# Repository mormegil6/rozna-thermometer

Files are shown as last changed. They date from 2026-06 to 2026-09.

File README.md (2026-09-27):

[]() []() []() []() []() []() 

# rozna-thermometer - Rožna Arduino Thermometer

A networked temperature monitor first built in 2015 in a student dorm on Rožna
dolina (Ljubljana), revived in 2026 for reliable, unattended temperature monitoring.
An Arduino **Leonardo** reads a **DS18B20** sensor, shows the temperature and an NTP
clock on a 16x2 LCD, and serves the original jQuery-Mobile web page plus a
`/list.json` API over Ethernet (**ENC28J60**).

The 2015 code is kept as the reference; the revival modernises it for current
toolchains, fixes the one thing that never worked back then (the ENC28J60 needed a
hardware reset), and adds resilience so it can run headless and unattended.

| 2015, the original build | 2026, the revived build | 2026, the public web UI |
|:---:|:---:|:---:|
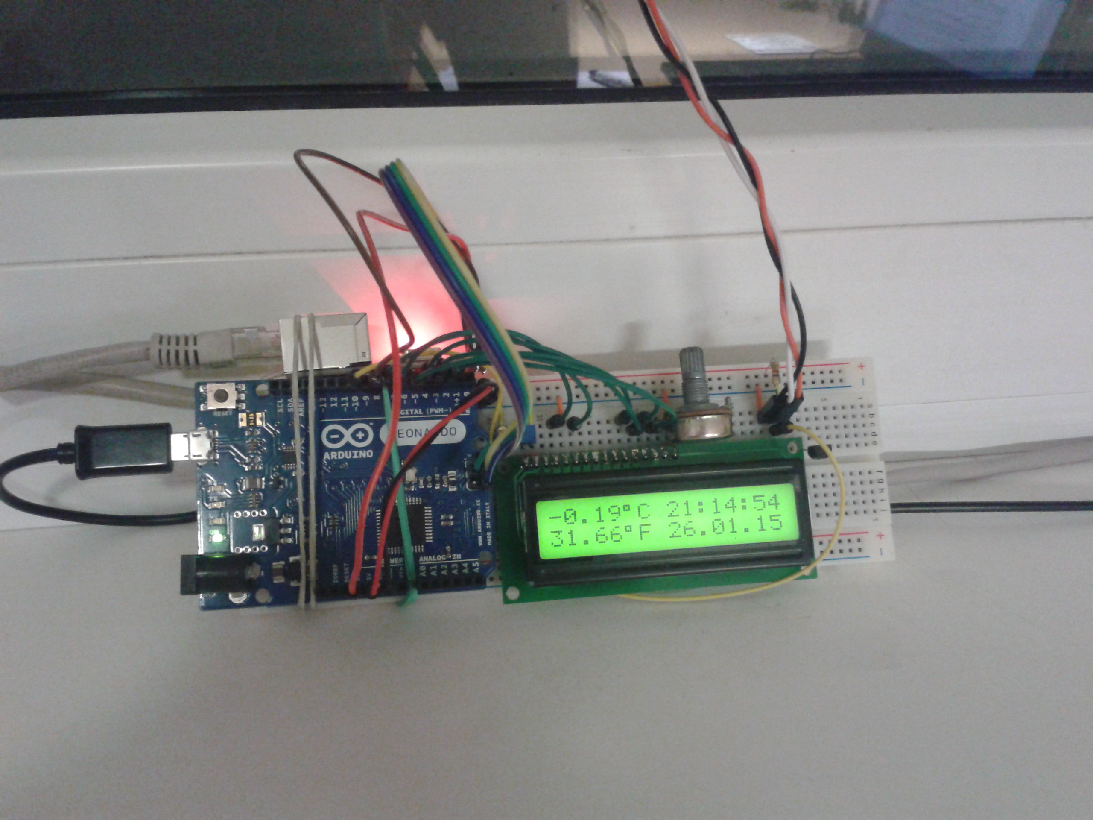
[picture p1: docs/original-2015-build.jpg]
The original 2015 breadboard build
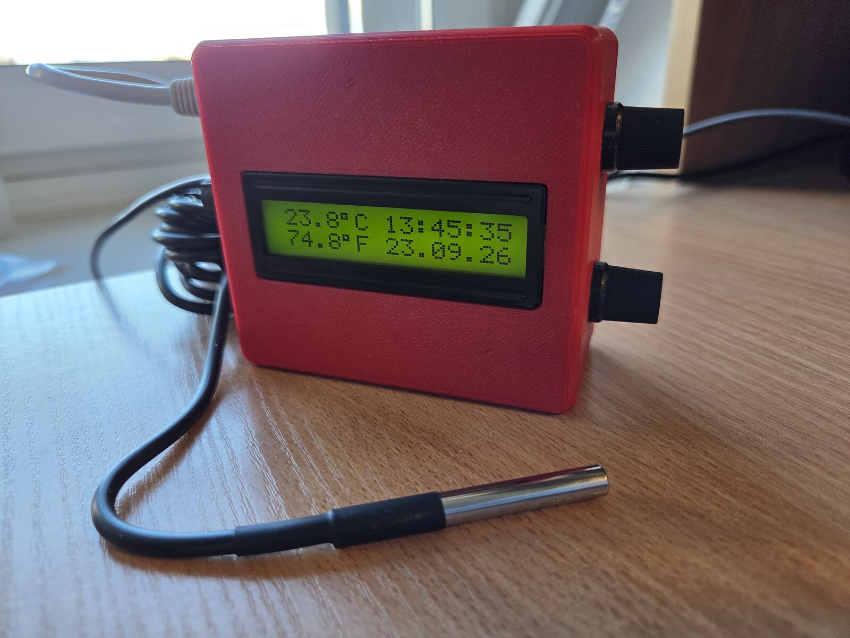
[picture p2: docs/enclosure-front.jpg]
The 2026 build in its 3D-printed enclosure, the DS18B20 probe on its cable in front
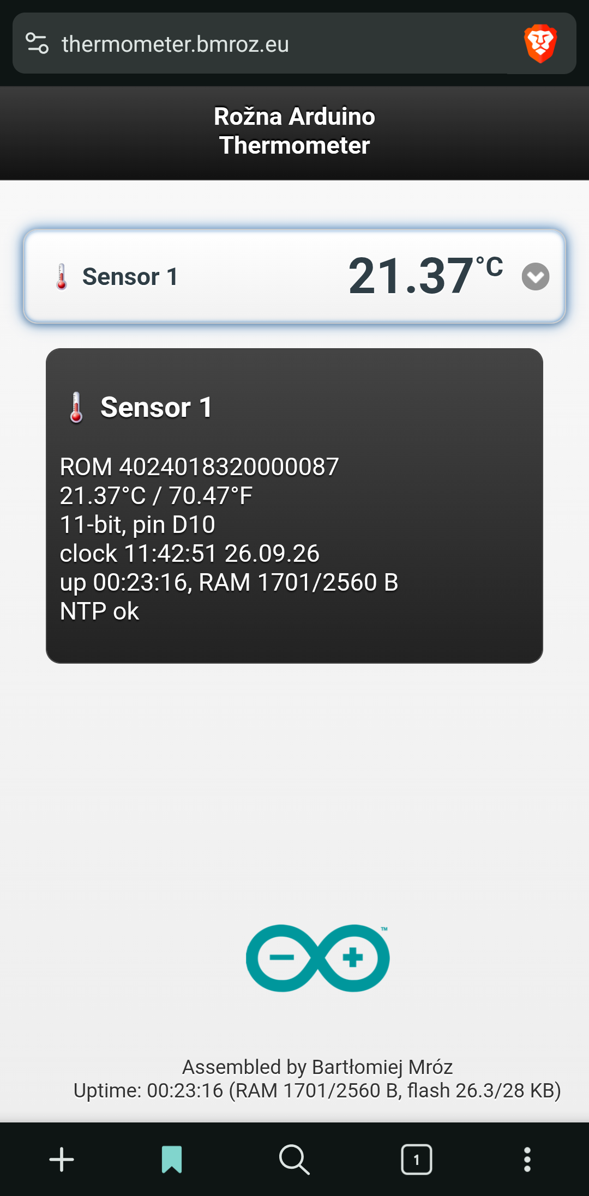
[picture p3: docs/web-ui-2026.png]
The web UI at thermometer.bmroz.eu in Brave on Android
|  |  |  |

*Left: the original 2015 build, LCD reading -0.19 C at 21:14 on 26 Jan 2015. Middle: the 2026 build in its 3D-printed enclosure, the DS18B20 probe on its cable in front. Right: the public web UI at [thermometer.bmroz.eu](https://thermometer.bmroz.eu) (Brave on Android) with a sensor's detail panel expanded. Click an image for the full size.*

## History

The original ran in a Ljubljana student dorm where the network was unusually open:
each room got two public, routable IP addresses (one per desk), so the thermometer's
page was reachable from the open internet, not just the LAN. Our room's router ran
OpenWrt with 802.1X on the WiFi, so we were the only ones online in there, which is
part of why a tiny ENC28J60 web server made sense at all. The 2026 revival runs on an
ordinary LAN, wherever it is plugged in, so the board itself is LAN-only. The page is
made public through a caching proxy and a Cloudflare tunnel on a Raspberry Pi instead
of a router port forward (see [Public access](#public-access)).

## Status

Working and validated on real hardware. The diagnostics pass, the modernised
sketch serves the original web UI and `/list.json`, NTP sets the clock, the
SleepyDog watchdog runs, and the Ethernet stack recovers from faults on its own.
Telegram alerting (Stage D) is designed but deferred (it lives off-device, on a
Raspberry Pi).

| Subsystem | State |
|---|---|
| Board, upload, Serial | working |
| 16x2 LCD (temperature + clock) | working |
| DS18B20 temperature | working |
| ENC28J60 Ethernet, web, `/list.json` | working (needs `RST` wired to D9, see below) |
| NTP clock | working |
| Watchdog and resilience | working |
| Public page, https://thermometer.bmroz.eu | working (nginx cache and Cloudflare tunnel on a Pi, see `pi/`) |
| Telegram alerting | deferred (Pi-side poller, see [Alerting](#alerting-possible-not-planned)) |

## Hardware and wiring

- **Arduino Leonardo** (ATmega32u4). Real ceilings: about 28 KB usable flash (a 4 KB
  bootloader eats into the 32 KB) and 2560 B of RAM. RAM is the tight one (the
  Ethernet buffer alone is over 1 KB).
- **ENC28J60** Ethernet module (EtherCard library)
- **DS18B20** temperature sensor (OneWire + DallasTemperature)
- **16x2 HD44780 LCD**, 4-bit, with a contrast potentiometer
- Powered over USB

### Pin map

| Signal | Leonardo pin | Notes |
|---|---|---|
| LCD | see LCD pin map below | 16x2 HD44780, 4-bit mode, `LiquidCrystal lcd(7,6,5,4,3,2)` |
| DS18B20 DATA | D10 | 4.7 kOhm pull-up DATA to 5V, required |
| ENC28J60 SPI (MISO/MOSI/SCK) | ICSP header | not pins 11/12/13 on a Leonardo |
| ENC28J60 CS | D8 | see Gotchas below |
| ENC28J60 RST | D9 | required, see Gotchas below |
| ENC28J60 VCC / GND | 3.3V (or 5V if the module has a regulator) / GND | |

**The probe plugs in through a 3.5 mm jack.** A small nod to my audio work these
days, and honestly just the first 3-pin connector that came to mind and was easy to
get. It works well, with two things to know. A plug bridges neighbouring contacts
while it is being inserted, so the layout matters for hot-plugging: tip = +5V, ring
(the middle contact) = GND, sleeve = DATA, which turns the unavoidable transient
shorts into +5V to GND and DATA to GND instead of +5V to DATA. And a series resistor
of 220 to 470 ohms in the +5V line is cheap insurance against a plug pulled out at an
angle. The 4.7 kOhm pull-up still has to bridge DATA to +5V as its own branch, not sit
in line with the signal.

### LCD pin map

| LCD signal | LCD header pin | Connects to | Notes |
|---|---|---|---|
| VSS | 1 | GND | |
| VDD | 2 | +5V | |
| V0 | 3 | contrast pot wiper | pot ends to 5V and GND |
| RS | 4 | Leonardo D7 | |
| RW | 5 | GND | not driven by the firmware, tied low |
| E | 6 | Leonardo D6 | |
| D0-D3 | 7-10 | not connected | 4-bit mode |
| D4 | 11 | Leonardo D5 | |
| D5 | 12 | Leonardo D4 | |
| D6 | 13 | Leonardo D3 | |
| D7 | 14 | Leonardo D2 | |
| A | 15 | +5V (through ~220R if the module has no onboard resistor) | backlight |
| K | 16 | GND | backlight |

**Gotchas.** The ENC28J60 needs a hardware reset: wire its `RST` to D9, or its PHY
never links (that was the 2015 "never appears on the router" bug). Keep its chip
select on D8, because EtherCard's default drifted to pin 17 on the Leonardo. Both are
set in the sketch. Connections on a breadboard are easily bumped loose, so solder or
use locking connectors for a permanent install. More in
[docs/hardware-notes.md](docs/hardware-notes.md).

### Enclosure

A 3D-printed enclosure, designed by Daniel Wiśniewski, a colleague from the
Department of Multimedia Systems, houses the board and brings the LCD, contrast
pot and brightness pot to the front panel. The two potentiometers are labelled
with brightness and contrast icons adapted from Flaticon (see [License](#license)
for credit). Design files are in [`enclosure/`](enclosure/): the full assembly
([`Termo_ass.step`](enclosure/Termo_ass.step)) and the two printable parts
([`Termo_box.stl`](enclosure/Termo_box.stl), [`Termo_lid.stl`](enclosure/Termo_lid.stl)).
A live, editable version is also on
[Fusion 360](https://mypg468.autodesk360.com/g/shares/SH28cd1QT2badd0ea72b3ebdcf2fd0c9138a).
The Leonardo's RESET button is inside the box, so a manual reset means opening the
lid (the firmware restarts itself when it has to).

| The knobs: brightness (top), contrast (bottom) | Inside, lid off (assembly, August 2026) | The lid carries the LCD (assembly, August 2026) |
|:---:|:---:|:---:|
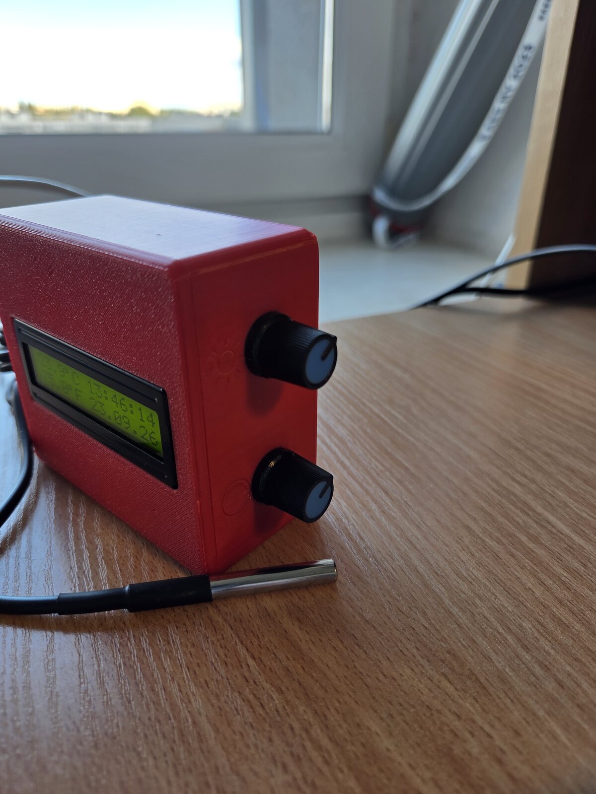
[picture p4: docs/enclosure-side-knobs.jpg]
Side of the enclosure with the brightness and contrast knobs and their embossed icons
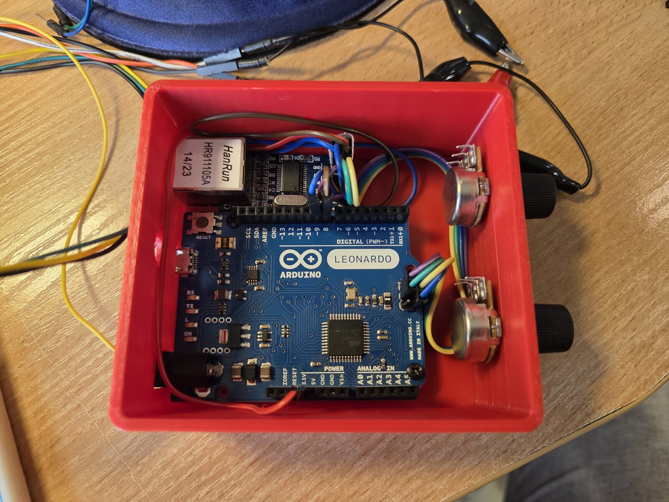
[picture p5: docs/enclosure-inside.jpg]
Inside the box: Leonardo, ENC28J60 module and the two potentiometers
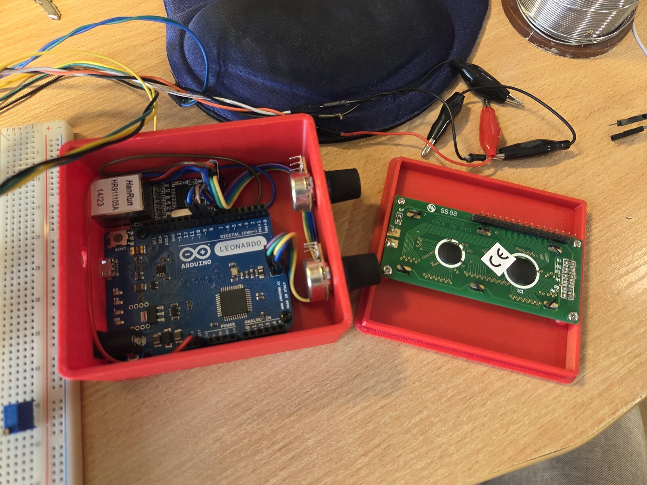
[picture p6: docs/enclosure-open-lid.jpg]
The open lid with the LCD's back and header
|  |  |  |

It is cramped and not pretty inside. These two were taken during assembly, before the
lid went on. The LCD's pin header was removed and wires were soldered straight to its
pads, because the header pins stuck out too far and collided with the Arduino's pin
sockets.

| Mid-wiring, wires soldered straight to the LCD (August 2026) | Wired up right before closing the lid (August 2026) |
|:---:|:---:|
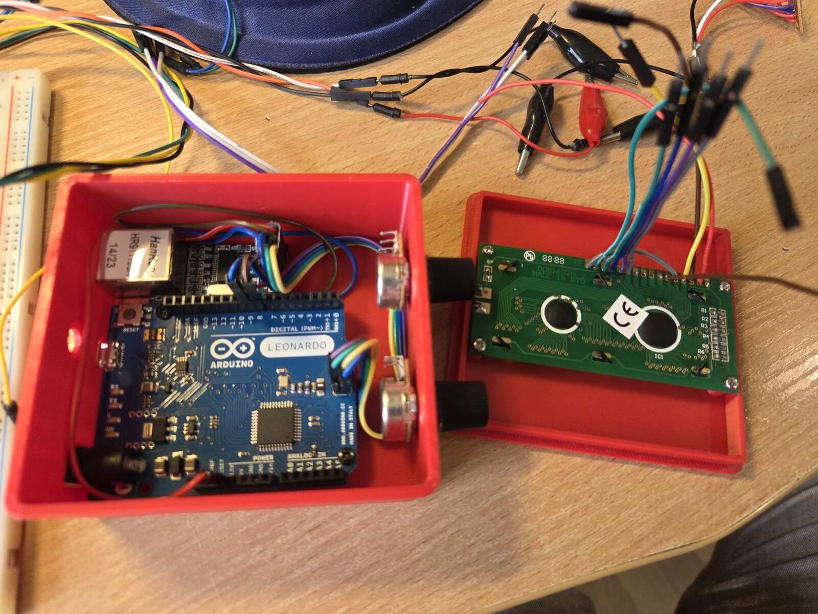
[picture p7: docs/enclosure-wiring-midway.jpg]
Box open with wires soldered directly to the LCD pads
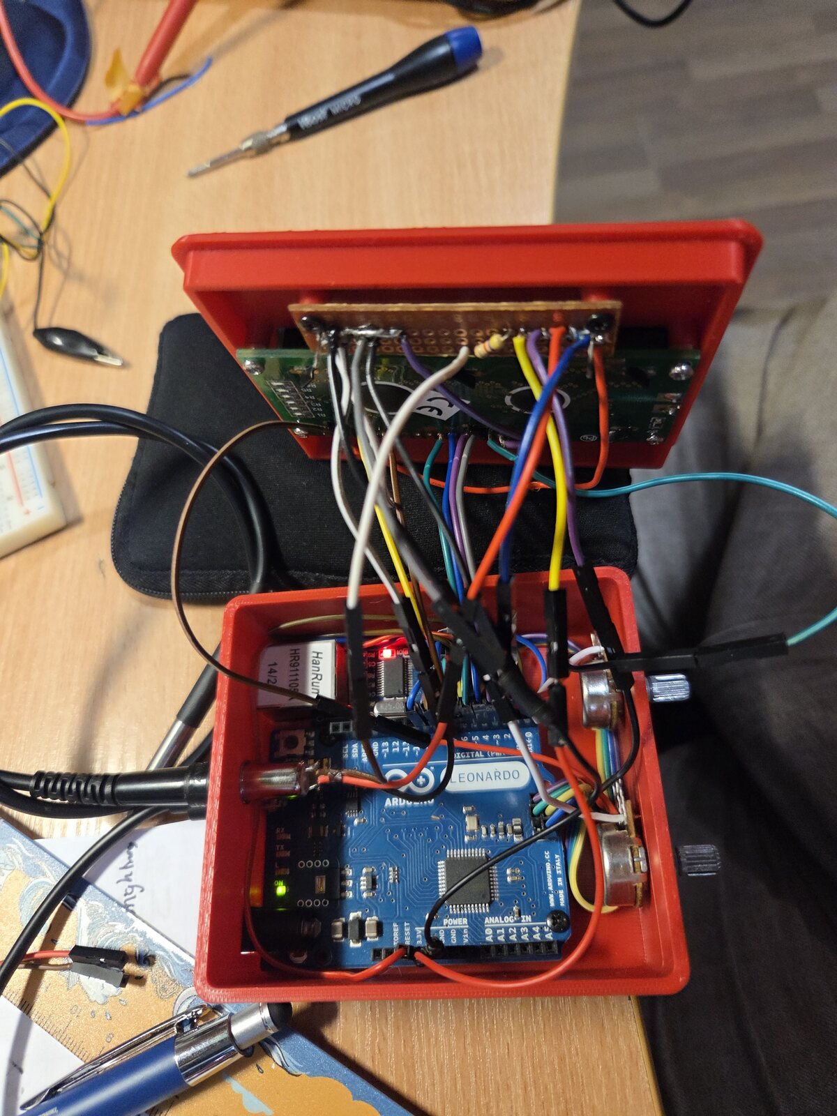
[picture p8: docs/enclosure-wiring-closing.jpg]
The finished wiring inside the box just before the lid was closed
|  |  |

## How it works

The Arduino serves the original 2015 jQuery-Mobile page (`/`, `main.css`, `main.js`,
`det.js`, `/favicon.svg`) and a `/list.json` API with the temperature and the health
fields. The heavy jQuery and jQuery-Mobile files load from `code.jquery.com`, because
284 KB would never fit in 28 KB of flash. The clock comes from NTP with a fixed server
IP (a DNS lookup used to freeze the whole loop), and EU summer time is computed on the
board. Sensor reads are asynchronous, so nothing waits on a 750 ms conversion. Details
and the JSON fields: [docs/how-it-works.md](docs/how-it-works.md).

### Resilience

The ENC28J60 is the weak link, so the firmware is built to survive it and to recover
without a person:

- A hardware reset over `RST` (D9) and a bounded SPI and oscillator check before
  `ether.begin()`, so a dead NIC never hangs the board. The LCD and the sensor keep
  working, and the NIC is retried every 15 s.
- The NIC is never re-initialised in place after traffic (EtherCard cannot resync its
  receive pointers). Instead a gateway ARP round trip proves the network path, and a
  watchdog restart of the MCU (about 5 s) follows 5 minutes of silence (2 once the chip has flagged a receive overflow) or 3 minutes
  without a link.
- The chip's key registers are checked every 10 s. The evidence (`rst`, `why`, `dbg`)
  survives a restart and is served in `/list.json`.
- Two LCD status cells stay blank when all is well: row 1 character 8 counts recent
  self-restarts, row 2 character 8 shows `O` (NIC offline), `L` (no link) or `S` (link
  up, no gateway reply).
- The DS18B20 can be plugged in at any time.

Full description: [docs/resilience.md](docs/resilience.md).

### Public access

The page is public at https://thermometer.bmroz.eu, but visitors never reach the
Arduino:

```
visitor -> Cloudflare (HTTPS) -> cloudflared on the Pi -> nginx cache on the Pi (127.0.0.1:8081) -> Arduino
```

A Raspberry Pi on the same LAN answers visitors from a cache and forwards about one
request per 10 s to the board, however many people watch. No router port is
forwarded, and none should be: the board speaks plain HTTP with no authentication.
Configs and setup steps: [pi/](pi/README.md).

## Build and upload

Built with **arduino-cli 1.5.1**, core **arduino:avr 1.8.8**, FQBN
`arduino:avr:leonardo`. Libraries:

| Library | Version |
|---|---|
| OneWire | 2.3.8 |
| DallasTemperature | 4.0.6 |
| EtherCard | 1.1.0 |
| Adafruit SleepyDog Library | 1.8.4 |
| Time | 1.6.1 |
| LiquidCrystal | 1.0.7 |

Footprint: about 26.3 KB of 28 KB flash (93 %), about 1.6 KB of 2.5 KB RAM (65 %).

```sh
# one-time setup
arduino-cli core install arduino:avr
arduino-cli lib install OneWire DallasTemperature EtherCard "Adafruit SleepyDog Library" Time LiquidCrystal

# find the port
arduino-cli board list                        # e.g. /dev/cu.usbmodem1101

# compile THEN upload (arduino-cli upload does NOT recompile, so always compile first)
arduino-cli compile -b arduino:avr:leonardo firmware/TempServerJQuery
arduino-cli upload  -b arduino:avr:leonardo -p <PORT> firmware/TempServerJQuery

# watch Serial at 9600
arduino-cli monitor -p <PORT> -c baudrate=9600
```

Bring up the subsystems first with the `diagnostics/` sketches (upload each, read
Serial), then flash the main sketch.

**If upload fails** with `butterfly_recv ... failed`, the Leonardo's 1200-baud
auto-reset did not reach the bootloader. See [docs/flashing.md](docs/flashing.md).

## Configuration (top of the sketch)

| Macro | Default | Meaning |
|---|---|---|
| `ETH_ENABLED` | `1` | `0` runs it as a pure thermometer, no NIC access at all |
| `USE_NTP` | `1` | `0` skips NTP and DNS; the LCD shows uptime and the web never stalls |
| `DEBUG` | `0` | `1` prints a 3 s Serial heartbeat; `0` is quiet and leaner |
| `SENSOR_RES` | `11` | DS18B20 resolution bits 9 to 12 (11 is 0.125 C, about 375 ms) |
| `CS_PIN` | `8` | ENC28J60 chip-select |
| `ETH_RST_PIN` | `9` | ENC28J60 hardware reset (comment out if unwired) |
| `ONE_WIRE_BUS` | `10` | DS18B20 data pin |
| `mymac` | `02:52:6F:7A:6E:61` | locally-administered MAC |
| `myip` / `gwip` / `dnsip` / `mask` | `192.168.1.200` / `.1` / `.1` / `/24` | the network it is deployed on |
| `UTC_STD_OFFSET_SEC` | `1*3600` | CET (winter) offset; EU summer time is added automatically |
| `PROBE_MS` / `AUDIT_MS` / `SILENT_RESTART_MS` / `SILENT_FAST_MS` / `LINK_DOWN_RESTART_MS` | 30 s / 10 s / 5 min / 2 min / 3 min | gateway ARP probe and chip register check intervals, then MCU restart when the gateway never replies or the link is lost |
| `ASSET_VER` | `"9"` | cache-bust version; bump when main.css/main.js/det.js change |
| `FOOTER_LOGO_URL` | ImgBB link | footer logo image |

For bench testing on a different subnet, change `myip` / `gwip` / `dnsip` (for
example to `192.168.0.x`).

## Diagnostics

Upload each, read Serial at 9600. Pass criteria:

| Sketch | Pass |
|---|---|
| `diag_01_blink` | on-board "L" LED blinks about 1 Hz; Serial prints `tick N` |
| `diag_02_lcd` | LCD shows `Rozna Thermo OK` and a live counter (adjust contrast if blank) |
| `diag_03_ds18b20` | `Found N device(s)`, a `28...` ROM with `CRC OK`, a plausible temperature |
| `diag_04_ethernet` | `ENC28J60 found, rev N`, IP set, `Link: UP`, answers `ping` |

## What changed since the 2015 code

The 2015 architecture was sound and is largely preserved. The changes are a few
modernisations, NTP instead of a serial time-sync, and a lot of reliability work (the
hardware reset was the real 2015 fix). See
[docs/changes-since-2015.md](docs/changes-since-2015.md).

## Known issues

- The ENC28J60 module is the weak link. Its 25 MHz oscillator can be intermittent (a
  cold solder joint on the crystal or its caps, or marginal power); a power-cycle plus
  the RST pulse revives it. If it stays flaky, reflow the crystal joints or replace
  the module (about 3 USD); the firmware and EtherCard code are unchanged either way.
- Latency is jittery (it is a slow 10 Mbps chip on breadboard wiring) but lossless
  once connected.
- Field failures on 2026-09-25 and 2026-09-26, cause not yet proven: the board stops
  answering ARP and TCP until it is restarted. The gateway ARP round trip now detects
  it and restarts the board by itself (it did on 09-26, after about 5 minutes), and the
  saved chip snapshot narrows the cause. Details in
  [docs/resilience.md](docs/resilience.md#field-failure-2026-09-25).
- The ENC28J60 module is powered from the Leonardo's 3.3 V pin, documented for only
  about 50 mA against 120 to 200 mA for the chip once linked. On 2026-09-26 its
  registers were repeatedly scrambled while the MCU kept running; the firmware
  restarted itself each time. A separate 3.3 V regulator for the module is the likely
  fix. Details in [docs/resilience.md](docs/resilience.md#chip-state-corruption-2026-09-26-hardware-suspected).
- A static-IP ENC28J60 takes no DHCP lease, so it might not appear in the router's
  device list; some routers list it anyway from ARP traffic they have seen. `ping`
  is the reliable check either way.

## Alerting (possible, not planned)

The ENC28J60 cannot do TLS, so the Arduino cannot call Telegram (HTTPS only)
directly. If this is ever wanted, a small poller on the Raspberry Pi that already
serves the public page (see [pi/](pi/README.md)) could fetch `/list.json` and send
an alert when the temperature crosses a threshold, keeping the Arduino dumb and
reusing infrastructure that already exists. Not being built right now.

## Repository layout

```
firmware/TempServerJQuery/TempServerJQuery.ino   the modernised sketch (static IP)
diagnostics/diag_01_blink/ ... diag_07_.../     bring-up and hardware diagnostic sketches
original-2015/                                    the untouched 2015 sketches (reference)
pi/                                               nginx cache and Cloudflare tunnel config for public access
enclosure/                                        enclosure design files (STEP, STL)
ardu_tempserver_logos/                            logo/icon source files
docs/                                             README images and the detailed notes
README.md  LICENSE  .gitignore
```

## License

MIT. See [LICENSE](LICENSE). The Arduino libraries this builds against are not
included and remain under their own licenses. The enclosure's brightness and
contrast icons are adapted from Flaticon: [Brightness icon](https://www.flaticon.com/free-icon/brightness_466300)
by Freepik, [Contrast icon](https://www.flaticon.com/free-icon/contrast_475980)
by Smartline, used under Flaticon's free license and not covered by the MIT
license above.

## Contact

Bartłomiej Mróz · bartlomiej.mroz@pg.edu.pl · Department of Multimedia Systems, Gdańsk University of Technology · [bmroz.eu](https://bmroz.eu)

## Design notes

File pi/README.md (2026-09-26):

# Pi side: public access without exposing the Arduino

The thermometer page is public at https://thermometer.bmroz.eu, but visitors never
reach the Arduino. A Raspberry Pi on the same LAN answers them from a cache and
forwards only a trickle of requests to the board.

```
visitor -> Cloudflare (HTTPS) -> cloudflared on the Pi -> nginx cache on the Pi (127.0.0.1:8081) -> Arduino (192.168.1.200)
```

The Arduino still serves the page, the scripts and `/list.json`. The Pi only caches
and relays. Nothing here changes the firmware.

## Why a cache is needed

The ENC28J60 is a 10 Mbit chip with one 1150 byte buffer, and every open browser tab
polls `/list.json` every 15 s. A handful of visitors, or one scanner, would keep it
busy or knock it over. With the cache in front, the board sees about one request per
10 s however many people watch.

What `nginx/thermometer.conf` and `nginx/thermo-proxy.conf` do:

- Listen on 127.0.0.1:8081 only. The Cloudflare tunnel is the only client.
- Proxy only the board's six URLs (`/`, `/list.json`, `/main.css`, `/main.js`,
  `/det.js`, `/favicon.svg`) and only GET. Everything else is refused by nginx itself
  (404, 400 or 403) and never reaches the board.
- Cache `/list.json` for 10 s, `/` for 60 s and the assets for 10 min (keyed by the
  `?v=` value, which must be 0 to 3 digits, so bumping `ASSET_VER` still works).
  Query strings on the other URLs are ignored, so they cannot bypass the cache.
- Collapse simultaneous cache misses into one request (`proxy_cache_lock`).
- Hold at most 2 connections open to the board (`max_conns=2`).
- Limit each visitor to 5 requests per second, burst 20, then answer 429. The visitor
  address comes from the `CF-Connecting-IP` header, trusted only from 127.0.0.1.
- Send the board a minimal request (`proxy_pass_request_headers off`). Cloudflare adds
  many headers, and the board's receive buffer is small.
- Keep the cache in RAM (`/dev/shm`) and write no access log.

Tested on the Pi: 800 requests from 800 different client addresses, 40 at a time,
caused exactly one request to the board. One address sending 100 requests as fast as
possible got 25 answers and 75 429s.

## Setup (Raspberry Pi OS or Debian, as root or with sudo)

### 1. nginx

```sh
sudo apt-get install nginx
sudo rm -f /etc/nginx/sites-enabled/default      # nothing should listen on port 80
sudo install -m 644 pi/nginx/thermometer.conf   /etc/nginx/conf.d/thermometer.conf
sudo install -m 644 pi/nginx/thermo-proxy.conf  /etc/nginx/snippets/thermo-proxy.conf
sudo nginx -t && sudo systemctl reload nginx
curl -i http://127.0.0.1:8081/list.json          # run twice: X-Cache goes MISS, then HIT
```

The board's address is in `thermometer.conf` (`192.168.1.200`) and in
`thermo-proxy.conf` (the `Host` header). Change both if the board's IP changes.

### 2. cloudflared

Debian has no `cloudflared` package, so add Cloudflare's own apt repository:

```sh
sudo mkdir -p --mode=0755 /usr/share/keyrings
curl -fsSL https://pkg.cloudflare.com/cloudflare-public-v2.gpg | sudo tee /usr/share/keyrings/cloudflare-public-v2.gpg >/dev/null
echo "deb [signed-by=/usr/share/keyrings/cloudflare-public-v2.gpg] https://pkg.cloudflare.com/cloudflared any main" | sudo tee /etc/apt/sources.list.d/cloudflared.list
sudo apt-get update && sudo apt-get install cloudflared
```

The domain's DNS must already be on Cloudflare. Then:

```sh
cloudflared tunnel login                 # prints a link; open it, pick the domain, authorize
cloudflared tunnel create thermometer    # prints the tunnel id, writes ~/.cloudflared/<id>.json
cloudflared tunnel route dns thermometer thermometer.bmroz.eu    # creates the CNAME
sudo mkdir -p /etc/cloudflared
sudo install -m 600 -o root -g root ~/.cloudflared/<id>.json /etc/cloudflared/<id>.json
# write /etc/cloudflared/config.yml from pi/cloudflared/config.yml.example, then:
sudo cloudflared service install
systemctl is-active cloudflared          # active
curl -i https://thermometer.bmroz.eu/list.json
```

`cert.pem` from the login lets the Pi create tunnels and DNS records for the whole
domain, and the running tunnel does not need it. Delete `~/.cloudflared/cert.pem`
once the tunnel works and log in again only when you add another hostname.

## Do not

- Forward a router port straight to the Arduino. It speaks plain HTTP with no
  authentication and a tiny TCP stack.
- Point anything public at the Arduino's address instead of the Pi.

## Behaviour when the board is down

After the 10 s cache expires visitors get an error from nginx. An already open page
keeps showing its last reading and retries every 15 s; it has no "stale" marker, so
the footer uptime standing still is the only hint.

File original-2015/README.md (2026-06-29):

# Original 2015 sketches (historical reference)

These are the untouched sketches from the 2015 build, kept to show how the project
evolved. They are not maintained and will not necessarily compile against current
libraries. For the working firmware see [`../firmware/TempServerJQuery/`](../firmware/TempServerJQuery/).

In date order (the commit dates match these):

| Date | File | What it was |
|---|---|---|
| 2015-01-25 | `thermometr_01.ino` | The earliest sketch: an LCD-only thermometer (C / F), no networking. |
| 2015-01-26 | `Exosite_tempServ.ino` | A variant that pushed readings to the Exosite IoT cloud (since defunct). |
| 2015-01-27 | `JQueryOrig.ino` | The jQuery-Mobile web UI (header "Is it hot?"), no LCD; DHCP or static IP selectable. |
| 2015-01-27 | `temp_server.ino` | A plain HTTP page ("My Arduino Website / Hello!"). |
| 2015-02-05 | `TempServerJQuery.ino` | The most complete variant: jQuery-Mobile UI + 16x2 LCD + clock + `/list.json`. The 2026 firmware is based on this one. |
| 2015-05-04 | `TempServerJQuery_noethernet.ino` | Same as above with Ethernet commented out, for LCD and clock bench testing. |

The file [`build-notes-2015.txt`](build-notes-2015.txt) is the original parts list from 2015
(the DS18B20 sensor, the LCD that sat on the window, the Arduino Leonardo, the ENC28J60
module, and the OpenWrt TP-LINK WR1043ND v2 router), together with the shell one-liner that
pushed the current time to the board over the serial port. The link shortener it used is long
dead, but the note is kept as found.

See the main [README](../README.md), section "What changed since the 2015 code", for the details.

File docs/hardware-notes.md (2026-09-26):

# Hardware notes

Wiring gotchas that cost time during bring-up. The pin maps are in the [README](../README.md#hardware-and-wiring).

**CS gotcha.** EtherCard's `begin()` default chip-select drifted from pin 8 (old)
to `SS`, which is pin 17 on the Leonardo (current library). The 2015 sketch relied
on the old default, so the real wiring is CS=8. The sketch sets `CS_PIN 8`
explicitly.

**RST gotcha (the actual 2015 bug).** The ENC28J60 needs a hardware reset pulse or
its PHY will not link. That was the original "never appears on the router" symptom.
Wire `RST` to D9; the firmware pulses it before every `ether.begin()`. Note that SPI
register reads are clocked by the Arduino, so the chip answers SPI even when its own
25 MHz crystal is not running. The firmware therefore also checks the
oscillator-ready bit (`CLKRDY`) before trusting it.

**Solid connections matter.** On a breadboard with dupont wires, bumping the board
can knock the ENC's SPI or power loose (this happened repeatedly during bring-up).
For a permanent install, solder or use locking connectors on the ENC's SPI, power
and RST lines.

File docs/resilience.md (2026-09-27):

# Resilience

How the firmware survives a flaky ENC28J60 and recovers without a person. The summary is in the
[README](../README.md#how-it-works).

## What it does

- Hardware reset of the ENC28J60 (`RST` to D9) before every bring-up.
- A bounded SPI plus CLKRDY probe before `ether.begin()`. `begin()` spins forever on
  an unresponsive chip, so it is never called unless the chip answers and its
  oscillator is running. A missing or dead NIC drops to OFFLINE: the LCD and sensor
  keep working and the firmware retries the NIC every 15 s.
- The NIC is never re-initialised in place once it may have received a frame.
  EtherCard keeps its receive pointers in function-local statics that
  `ether.begin()` cannot reset, so an in-place re-init leaves the receive path out of
  step with the chip: the board still transmits but never answers ARP or ping. A lost
  link is simply waited out (the receive ring is untouched), and if the chip does not
  resume when the link returns, the ladder below restarts the MCU.
- Recovery ladder. With the link up the board sends an ARP request to the gateway
  every 30 s, and only the gateway's reply counts as proof of life: it needs a short
  frame to leave the board and a reply to come back, whereas any received frame would
  hide a chip that receives but cannot send. The MCU restarts with a watchdog reset
  (about 5 s, which also clears the EtherCard pointers) after 5 min without a reply (2 min once the chip has flagged a receive
  overflow),
  3 min with the link down after it was up, a NIC fault after traffic, or the chip's
  key registers (ECON1.RXEN, MACON1, MACON3, ERXFCON, the MAC address) changing on two
  checks 10 s apart. Consecutive restarts stretch the windows up to 4 times, and 30
  min of healthy uptime forgets them. The clock survives a restart. `gwip` must
  answer ARP, otherwise a bench board with no gateway restarts at 5, 10 and then every 20 min.
- Evidence for the next failure. Before a self-restart the chip's registers are read
  (12 bytes: ECON1 ESTAT EIR MACON1 MACON3 ERXFCON, a mask of wrong MAC bytes,
  EPKTCNT, then the receive buffer pointers ERXRDPT and ERXWRPT, low byte first),
  printed on Serial, kept in RAM across the restart and served as `why` and `dbg` in
  `/list.json`. The read restores ECON1.BSEL, so EtherCard's cached register bank
  stays valid. At every boot Serial shows `Chip audit OK` when the registers match
  what EtherCard configured, or `Chip audit BAD` with the bytes. The chip's own reset
  clears its sticky error flags (EIR.RXERIF, EIR.TXERIF, ESTAT.BUFER), so a flag seen
  later means an overflow or error since the last bring-up. Serial also prints the
  link changes with the uptime, the snapshot when the first gateway probe goes
  unanswered, a one-time "RX overflow flag" line, and a snapshot whenever you send `d`
  over USB.
- Receive buffer pointer. ENC28J60 errata item 14 says an even ERXRDPT can corrupt
  the receive buffer, including the next packet pointer of a frame. EtherCard's
  `initialize()` leaves ERXRDPT at 0, and its own steady state writes only odd values
  (next packet pointer minus 1, or ERXND). After every successful `ether.begin()` the
  sketch therefore writes ERXRDPT = ERXND (0x0BFF), the value EtherCard itself writes
  when the next packet is at 0, so the first frames after a bring-up no longer arrive
  with an even pointer. Whether this was behind the 09-25 and 09-26 failures is
  unproven.
- LCD status cells, both blank when all is well: row 0 column 8 shows recent
  self-restarts (`+` above 9) and clears itself after 30 min of healthy uptime, row 1
  column 8 is `O` for NIC offline, `L` for no link and `S` for link up but no
  gateway ARP reply for 90 s. The lifetime restart count is `rst` in `/list.json`.
- The DS18B20 can be plugged in at any time. DallasTemperature only counts devices in
  `begin()`, so a probe attached after boot used to stay invisible; while none is
  known the sketch checks the bus every 3 s and re-runs `begin()` when one appears.
- SleepyDog watchdog (8 s), safe on the 32u4 bootloader.
- Temperature and LCD are fully decoupled from the network, so the monitor always
  works.

## Field failure, 2026-09-25

Cause not yet proven: LCD, clock and link LEDs
fine, but the board answered ping (with a static ARP entry) and never answered ARP
or completed a TCP handshake, from wired and Wi-Fi clients alike. Every frame the
firmware sends with an explicit short length (the 42 byte ARP reply, the SYN-ACK)
was lost, while echo replies, which copy the incoming length, were fine. The
suspect is the chip no longer padding short frames (MACON3), so the router drops
them; a power cycle fixed the same symptom the day before. The gateway ARP round
trip now detects it and the register snapshot should show which register changed.

## Second occurrence, 2026-09-26, and the first recovery in the field

After a reflash the board booted with no Ethernet cable, and the cable was plugged in
about a minute later. For the next five minutes the board sent an ARP request for the
gateway every 3 s or so (visible on the LAN) but answered nothing, so there was no ping,
no web page and no NTP. The LCD showed `S` after 90 s. At about 6 minutes of uptime it
restarted itself (`why` 2, no gateway ARP reply with the link up) and was back with NTP
and the web page about 90 s later, with `rst` 1 and no human involved.

The saved chip snapshot was `[5, 65, 9, 1, 50, 177, 0, 0]`. Every register the audit
checks was exactly as EtherCard configured it (ECON1 0x05 with RXEN set, MACON1 0x01,
MACON3 0x32, ERXFCON 0xB1, MAC bytes correct), so the register audit could not see this
fault and the gateway ARP ladder did. Two sticky flags stand out: ESTAT.BUFER (0x40)
and EIR.RXERIF (0x01) were set, meaning the chip's receive buffer overflowed at some
point since power-up (EtherCard never clears them), while EIR.PKTIF was clear (no packet
pending at that instant). That fits a receive path that got out of step, but it does not
prove it: the flags could also come from a burst of traffic during boot. It also weakens
the padding theory from 09-25, because MACON3 was correct this time.

## Reading the snapshot

The 12 bytes are ECON1, ESTAT, EIR, MACON1, MACON3, ERXFCON, a mask of wrong MAC
bytes, EPKTCNT, ERXRDPT (low, high) and ERXWRPT (low, high). A healthy idle chip looks
like `05 01 08 01 32 B1 00 00 xx yy xx+1 yy` with EPKTCNT 0 and ERXWRPT one ahead of
ERXRDPT (EtherCard writes ERXRDPT as the next packet pointer minus 1). A gap of about
one frame right after traffic is only EtherCard releasing a frame lazily. The suspicious
signature is EIR.RXERIF and ESTAT.BUFER set with EPKTCNT 0, and ERXWRPT just below
ERXRDPT or garbage. The pointer bytes are only reliable when the link is quiet: ERXWRPT
updates when a frame completes and the two bytes are read a fraction of a millisecond
apart.

## Chip state corruption, 2026-09-26 (hardware suspected)

On the afternoon of 09-26 the chip's registers were repeatedly scrambled while the MCU
kept running. Snapshots showed ESTAT.CLKRDY clear, MACON1, MACON3 and all six MAC bytes
wrong, nonsense buffer pointers, or every register reading 0. It happened on USB power
from a Mac (whose connector was loose) and on a wall adapter, 50 to 130 s after each
restart, six self-restarts between 12:53 and 13:11. Then it stopped for more than 45
minutes with no change made. The firmware caught it every time (`enc28j60Healthy()`
notices RXEN or CLKRDY lost) and restarted, but because the restart windows double, each
recovery took one to four minutes.

Suspected, not confirmed: the module is powered from the Leonardo's 3.3 V pin, whose
documented limit is about 50 mA, while an ENC28J60 module draws roughly 120 to 200 mA
once linked. A regulator that small can overheat or sag, especially inside a closed box.
An intermittent SPI or power connection is the other candidate. Next steps: give the
module its own 3.3 V regulator, check the SPI wires, and audit ERXST, ERXND and ERXRDPT
too, so a scrambled chip is caught faster.

## EtherCard cannot be re-initialised in place

EtherCard 1.1.0 cannot be re-initialised in place after it has received a frame
(`packetReceive()` keeps private static pointers that `ether.begin()` does not
reset). Do not call `ether.begin()` again from your own code once traffic has
flowed; the firmware restarts the MCU instead. Confirmed in the source and a
simulation, not yet on hardware.

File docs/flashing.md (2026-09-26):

# Flashing when the automatic reset fails

The normal steps are in the [README](../README.md#build-and-upload).

**If upload fails (`butterfly_recv ... failed`).** The Leonardo's 1200-baud
auto-reset can stop dropping the board into the Caterina bootloader (common after
many upload cycles, or with a watchdog sketch), and arduino-cli then flashes against
the running sketch and fails. Recovery: double-tap RESET (the "L" LED pulses, which
means the bootloader is up for about 8 s) and flash with avrdude directly, bypassing
the 1200-baud touch:

```sh
AV=~/Library/Arduino15/packages/arduino/tools/avrdude/8.0.0-arduino1
# the hex path is shown by:  arduino-cli upload -v ...   (under ~/Library/Caches/arduino/sketches/<hash>/)
"$AV/bin/avrdude" "-C$AV/etc/avrdude.conf" -patmega32u4 -cavr109 -P<PORT> -b57600 -D \
  -Uflash:w:<sketch>.ino.hex:i
```

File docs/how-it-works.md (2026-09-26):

# How it works

The detail behind the summary in the [README](../README.md#how-it-works).

## Web UI and API

The Arduino serves only a small HTML shell plus `main.css`, `main.js`, `det.js` and
`/list.json`. The heavy assets (jQuery 1.8.2, jQuery-Mobile 1.2.0 js+css,
`date.format.js`) are loaded by the browser from `code.jquery.com` over HTTPS; at
about 284 KB they would never fit in 28 KB of flash. This is the original 2015
architecture, preserved.

- `GET /` serves the HTML shell (header "Rožna Arduino Thermometer", inset
  listview, footer).
- `GET /main.css`, `GET /main.js`, `GET /det.js` are served from PROGMEM.
- `GET /list.json` returns `{"list":[{"id","name","val","ifnegative"}],"uptime","free","flash","res","pin","ntp","now","rst","why","dbg"}`,
  where `val` is degrees C times 100 (the JS divides by 100), `free` is free RAM and
  `flash` the program size in bytes (read from the linker, so it matches the IDE's
  "Sketch uses N bytes" and is never stale), `now` is local time,
  `rst` counts self-restarts since power-up, `why` is the reason code of the last
  self-restart (0 none, 1 no link, 2 no gateway ARP reply, 3 NIC re-init after
  traffic, 4 chip registers changed) and `dbg` is the chip snapshot taken just
  before it (see [resilience.md](resilience.md)). The footer shows the
  "Assembled by Bartłomiej Mróz" credit, uptime, and memory use (RAM used / total in
  bytes, flash used / total in KB, both read from the running board).
- Tapping a sensor row slides open an inline detail panel (and rotates the row's
  arrow 90 degrees): ROM id, C and F, resolution, data pin, the NTP clock (same as
  the LCD), uptime, RAM use and NTP status. Tap again to collapse.

**Images.** The browser-tab icon is a self-contained thermometer emoji served as a
tiny SVG from its own `/favicon.svg` route. The footer logo (`ardu.png`) is a raster
image, browser-loaded from an external host (`FOOTER_LOGO_URL`, currently ImgBB);
the Arduino never serves image bytes. Static assets are cache-busted with a `?v=`
version (`ASSET_VER`), so changes reach the browser without a manual cache clear.

## NTP clock

Replaces the original serial time-sync, which froze the board at boot waiting for a
PC. `serviceTime()` sends an NTP request to a fixed server IP (Google Public NTP,
`NTP_SERVER_IP`) rather than a hostname: `ether.dnsLookup()` can block for about 30 s
when a query gets no reply, and that froze the whole loop, LCD included. The answer
sets the Time library clock, which holds UTC. `localNow()` adds the Polish offset
(CET, plus EU summer time from 01:00 UTC on the last Sunday of March to 01:00 UTC on
the last Sunday of October) for the LCD and the JSON `now`. It re-syncs hourly, and
until the first answer the LCD shows uptime.

## Performance

- **Non-blocking sensor.** DS18B20 conversions run asynchronously
  (`waitForConversion=false`), started on a timer and read about `CONV_DELAY_MS`
  later. Neither the LCD nor `/list.json` waits on a conversion, so `/list.json`
  answers in about 40 ms. The old code blocked roughly 750 ms, twice.
- **Browser caching.** `main.css`, `main.js`, `det.js` and `favicon.svg` are sent
  with `Cache-Control: max-age=86400`; only `/list.json` is `no-cache`.
- **LCD in place.** It repaints without `lcd.clear()` (no flicker), about twice a
  second so the seconds never skip, and temperatures are formatted with integer
  math so the float-to-string code is never linked.

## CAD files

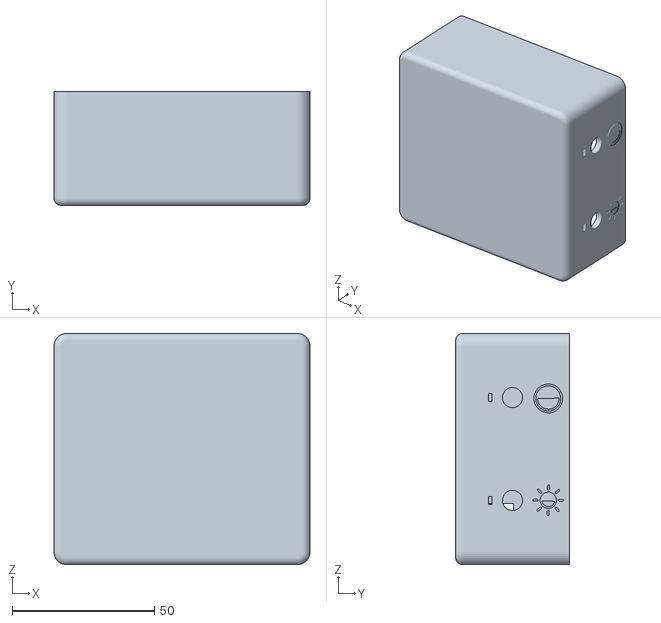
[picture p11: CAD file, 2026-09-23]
enclosure/Termo_box.stl
90.0 x 40.0 x 81.3

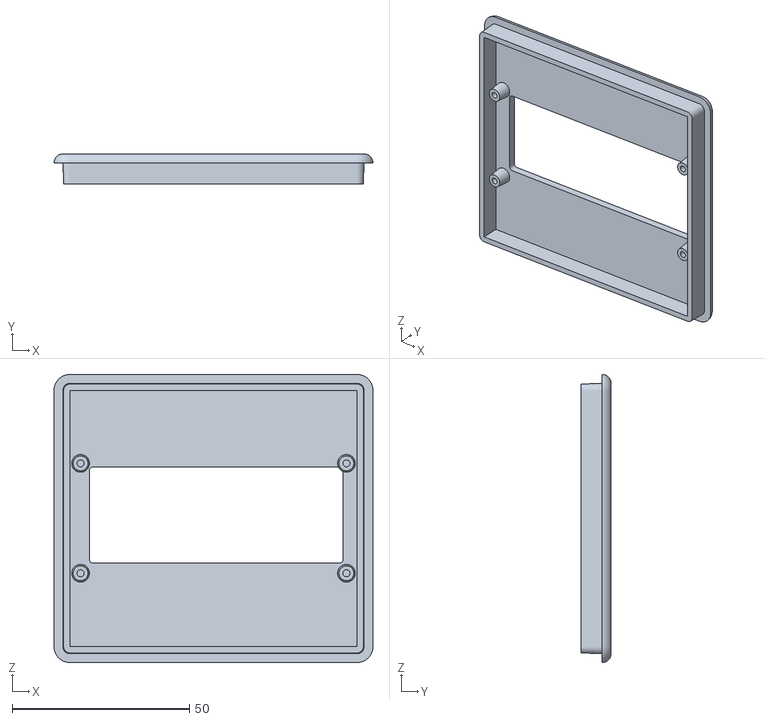
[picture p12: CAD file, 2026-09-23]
enclosure/Termo_lid.stl
90.0 x 8.50 x 81.3

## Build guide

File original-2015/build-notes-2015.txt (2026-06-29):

the components:
DS18B20 digital temperature sensor http://ujeb.se/IPXp
LCD display (it stays on my window, for me to see it without a need to go to the Internet) http://ujeb.se/9TjU
Arduino Leonardo - programmable prototype board, which is the heart of the whole thing http://ujeb.se/xLqq
Ethernet module enc28j60 http://ujeb.se/YTtM
Router TP-LINK WR1043ND v2 with alternative software installed, OpenWRT http://ujeb.se/RNrL

sudo echo "T$(($(date +%s)+2*60*60))" >/dev/ttyACM0

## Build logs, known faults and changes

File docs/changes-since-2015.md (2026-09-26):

# What changed since the 2015 code

The 2015 architecture was sound and is largely preserved: the web design,
`/list.json`, the HTTP parser, sensor enumeration and LCD layout are essentially
unchanged. The changes fall into three buckets.

**Trivial modernisation**

- MAC changed from the textbook `DE:AD:BE:EF:FE:ED` to a locally-administered `02:..`
- Explicit `CS=8` (EtherCard's default CS drifted to `SS`, pin 17, on the Leonardo)
- `<Time.h>` to `<TimeLib.h>`; verified against current DallasTemperature, OneWire and EtherCard
- CDN tags switched from protocol-relative `//` to `https://`
- Removed the dead `s3.postimg.org` footer image; kept the credit, uptime and free-RAM footer

**One feature swap**

- NTP replaces serial time-sync, so the board no longer freezes at boot waiting for
  a connected PC and keeps real time headless.

**Reliability, the bulk of the new code and the real 2015 fix**

- Hardware reset of the ENC28J60 over `RST` to D9, the missing piece that made the
  PHY actually link (the original "never appears on the router" bug).
- An SPI plus CLKRDY probe before `ether.begin()`, so a missing, dead or
  half-connected NIC can never hang the board; it degrades to OFFLINE and retries.
- SleepyDog watchdog (safe on the 32u4).
- A fixed NTP server IP instead of a DNS lookup, because a blocking lookup froze the
  whole loop, LCD included, whenever a query got no answer.
- No in-place NIC re-init after traffic (EtherCard cannot resynchronise its receive
  pointers), and a restart ladder for a dead receive path (see [resilience.md](resilience.md)).
- Automatic EU summer time for the LCD clock.
- Temperature and LCD decoupled from Ethernet; a Serial heartbeat for observability.
- Async sensor reads, browser-cached static assets with cache-busting, integer
  formatting, 11-bit DS18B20, and the expandable per-sensor detail panel.

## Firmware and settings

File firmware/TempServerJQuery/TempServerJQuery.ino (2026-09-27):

/*
 * Rožna Arduino Thermometer — modernized core sketch (2026 revival)
 * Original built 2015 (Ljubljana). Assembled by Bartłomiej Mróz.
 *
 * Board: Arduino Leonardo (ATmega32u4).  Ceilings: ~28 KB flash, 2560 B RAM.
 * Hardware:
 *   - DS18B20 on D10 (OneWire + DallasTemperature), 4.7k pull-up DATA->5V
 *   - 16x2 HD44780 LCD, 4-bit: RS=D7 E=D6 D4=D5 D5=D4 D6=D3 D7=D2, RW=GND
 *   - ENC28J60 (EtherCard): SPI via the Leonardo ICSP header, CS=D8, RST=D9
 *       NOTE: do NOT rely on EtherCard's default CS — it drifted from pin 8
 *       (old) to SS=pin 17 (current) on the Leonardo. We force CS=8 here to
 *       match the known-good 2015 wiring (see diagnostics/diag_04_ethernet).
 *       RST->D9 is REQUIRED: the module needs a hardware-reset pulse or its PHY
 *       won't link (this was the actual 2015 "never appears on the router" bug).
 *
 * What changed vs the 2015 sketch:
 *   - MAC is now locally-administered (02:..) instead of DE:AD:BE:EF:FE:ED.
 *   - Office static IP 192.168.1.200 / gw .1 / mask /24, DNS = gateway.
 *   - Serial time-sync (which froze the board at boot waiting for a PC) is
 *     replaced by NTP over EtherCard; LCD falls back to uptime if NTP is
 *     unavailable, so the board NEVER blocks at boot.
 *   - Adafruit SleepyDog watchdog (safe on the 32u4 bootloader).
 *   - ENC28J60 resilience: a hardware RST pulse (D9) plus a bounded SPI probe
 *     BEFORE ether.begin() (which otherwise spins forever on an unresponsive
 *     chip). If the NIC is missing/flaky the board runs OFFLINE (LCD + sensor
 *     only) and keeps retrying in the background — temperature monitoring never
 *     depends on the network. This is the "adapter dies, needs a restart" fix.
 *   - Web assets (jQuery / jQuery-Mobile / date.format) load from the
 *     code.jquery.com CDN over HTTPS; the Arduino still serves only the tiny
 *     HTML shell + main.css + main.js + /list.json (the 284 KB of JS/CSS can
 *     never fit in 28 KB of flash).
 *   - Dead s3.postimg.org footer image removed; the "Assembled by …" credit,
 *     uptime and free-RAM footer are kept.
 *
 * Alerting (Telegram) is intentionally NOT here: the ENC28J60 can't do TLS,
 * so a poller on the Raspberry Pi reads /list.json and sends alerts. The
 * Arduino stays "dumb". See README.
 */

#define REQUIRESALARMS false        // DallasTemperature: no alarm code

#include <OneWire.h>
#include <DallasTemperature.h>
#include <EtherCard.h>
#include <SPI.h>
#include <LiquidCrystal.h>
#include <TimeLib.h>
#include <Adafruit_SleepyDog.h>
#include <avr/wdt.h>

// ----------------------------- configuration -----------------------------
#define ETH_ENABLED     1           // set 0 to run as a pure thermometer (no NIC access at all)
#define USE_NTP         1           // set 0 to skip NTP entirely (LCD shows uptime; web never stalls)
#define DEBUG           0           // 1 = print a 3 s Serial heartbeat; 0 = quiet + leaner for deployment
#define CS_PIN          8           // ENC28J60 chip-select (NOT the SS default!)
#define ETH_RST_PIN     9           // ENC28J60 RST (active-low) -> wire to D9. Comment out if unwired.
#define ONE_WIRE_BUS    10          // DS18B20 data pin

// Office network (192.168.1.x). Edit here if your subnet differs.
static byte mymac[] = { 0x02, 0x52, 0x6F, 0x7A, 0x6E, 0x61 };   // locally-administered "02 R o z n a"
static byte myip[]  = { 192, 168, 1, 200 };
static byte gwip[]  = { 192, 168, 1, 1 };
static byte dnsip[] = { 192, 168, 1, 1 };   // router usually serves DNS; use 8.8.8.8 if not
static byte mask[]  = { 255, 255, 255, 0 };

// LCD clock zone: standard (winter) offset, Poland/CET = +1 h. EU summer time is added in localNow().
#define UTC_STD_OFFSET_SEC  (1L * 3600L)
// Fixed NTP server IP (Google Public NTP), not a hostname: ether.dnsLookup()
// can block for ~30 s with the watchdog paused if a query never gets a reply,
// freezing the LCD along with everything else. Skipping DNS entirely removes
// that risk; the actual time request below is already non-blocking.
static const byte NTP_SERVER_IP[] = { 216, 239, 35, 4 };
#define NTP_SRCPORT     0x42
#define NTP_SYNC_MS     3600000UL           // resync once an hour after first success
#define NTP_RETRY_MS    20000UL             // retry this often until first success
#define ETH_REINIT_MS   30000UL             // link never came up this long: re-init in place
#define ETH_RETRY_MS    15000UL             // when offline, re-probe + bring up the NIC this often
#define LINK_CHECK_MS   2000UL              // how often to read PHY link status
#define PROBE_MS        30000UL             // link up: ARP the gateway this often
#define AUDIT_MS        10000UL             // read the chip's key registers this often once the boot audit passed
#define SILENT_RESTART_MS 300000UL          // link up and no gateway ARP reply this long: restart the MCU
#define SILENT_FAST_MS  120000UL            // same, but once the chip has flagged a receive overflow (jam evidence)
#define LINK_DOWN_RESTART_MS 180000UL       // link down this long after it was up: restart the MCU
#define BACKOFF_MAX     2                   // consecutive restarts double the windows, up to 4x (was 16x: a bad night on 2026-09-26/27 showed a dead chip waiting up to 160 min for LINK_DOWN_RESTART_MS<<4)
#define STREAK_CLEAR_MS 1800000UL           // this much healthy uptime forgets earlier restarts
#define MIN_UPTIME_MS   60000UL             // minimum uptime before a NIC-fault restart
#define WDT_MS          8000                // SleepyDog window (AVR max ~8s)
#define LCD_REFRESH_MS  500                 // repaint ~2x/s so the seconds clock never skips
#define SENSOR_RES      11                  // DS18B20 resolution bits 9..12 (11 = 0.125 C, ~375 ms)
#define SENSOR_INTERVAL_MS 1500             // start a new (async) conversion this often
#define SENSOR_RESCAN_MS 3000UL             // no probe known: look for a newly plugged one this often
#define CONV_DELAY_MS   ((750 >> (12 - SENSOR_RES)) + 40)   // wait for conversion before reading
#define NTP_EPOCH_1900  2208988800UL        // seconds between 1900 and 1970

// The footer logo is a real raster image, so it's browser-loaded from an external
// host (the Arduino can't serve binaries: 28 KB flash + a ~1 KB page buffer).
// Currently on ImgBB; swap for your own host / public-repo jsDelivr URL anytime.
#define FOOTER_LOGO_URL "https://i.ibb.co/BKN52Q7w/arduino-logo-hugodemiglio.png"  // 256x256, downscaled in CSS
#define ASSET_VER       "9"         // cache-bust: bump when main.css/main.js/det.js change so browsers refetch
// The favicon stays the self-contained 🌡️ emoji, but is served from its OWN tiny
// route (/favicon.svg) and referenced by a SHORT href — so it never bloats the
// home page. (Inlining it as a data: URI overflowed the buffer and reset the board.)

// ------------------------------- objects ---------------------------------
OneWire oneWire(ONE_WIRE_BUS);
DallasTemperature sensors(&oneWire);
LiquidCrystal lcd(7, 6, 5, 4, 3, 2);        // RS, E, D4, D5, D6, D7
byte Ethernet::buffer[1150];                // TCP/IP send+receive buffer: must hold the whole frame (Eth/IP/TCP headers + the largest HTTP response). With the detail JS split into det.js the largest response is the home page (~1 KB), so this fits with margin.
static BufferFiller bfill;

// -------------------------------- state ----------------------------------
static uint8_t  ntpServerIp[IP_LEN];
static bool     haveNtpServer = false;
static bool     timeSynced    = false;
static uint32_t lastNtpReq    = 0;
static uint32_t lastLinkUp    = 0;
static uint32_t lastLcd       = 0;
#if DEBUG
static uint32_t lastStatus    = 0;
#endif
static uint32_t lastEthTry    = 0;
static uint32_t lastLinkChk   = 0;
static uint32_t lastAck       = 0;       // last ARP reply from the gateway, or last link DOWN to UP edge
static uint32_t lastProbe     = 0;
static bool     probeMiss     = false;   // a probe went unanswered (noted once on Serial)
static bool     ovfSeen       = false;   // the RX overflow flag was noted once on Serial
static bool     auditOk       = false;   // the boot audit passed, so a later mismatch is drift, not a misread
static uint8_t  auditBad      = 0;       // consecutive periodic audits that failed
static uint32_t lastAudit     = 0;
static bool     rxSeen        = false;   // link came up or a frame was read: never re-init the chip in place
static bool     ethReady      = false;   // true only when ether.begin() has succeeded
static bool     linkUp        = false;   // cached PHY link state (updated on a timer)
float celsius, fahrenheit;
static bool     haveReading   = false;   // true once we have a valid reading
static bool     converting    = false;   // an async DS18B20 conversion is in progress
static uint32_t convStart     = 0;
static uint32_t lastConvReq   = 0;
static uint32_t lastRescan    = 0;

// Survive a watchdog restart (.noinit is neither cleared nor initialised at startup).
#define NV_MAGIC 0xB007
static uint16_t nvMagic  __attribute__((section(".noinit")));   // NV_MAGIC after restartMcu() only
static uint8_t  nvStreak __attribute__((section(".noinit")));   // consecutive self-restarts
static uint8_t  nvTotal  __attribute__((section(".noinit")));   // self-restarts since power-up (JSON, Serial)
static uint32_t nvTime   __attribute__((section(".noinit")));   // UTC clock across a restart, 0 = none
static uint8_t  nvWhy    __attribute__((section(".noinit")));   // reason code of the last self-restart, 0 = none
#define DBG_LEN 12                       // chip snapshot bytes, see encSnapshot()
static uint8_t  nvDbg[DBG_LEN] __attribute__((section(".noinit")));   // chip snapshot taken just before it

// ------------------------------- helpers ---------------------------------
// Caterina already clears MCUSR and stops the watchdog; this covers a bootloader that does not.
void wdtEarlyOff() __attribute__((naked, used, section(".init3")));
void wdtEarlyOff() { MCUSR = 0; wdt_disable(); }

static void encSnapshot(uint8_t out[DBG_LEN]);

// Chip snapshot bytes: ECON1 ESTAT EIR MACON1 MACON3 ERXFCON MAC-mismatch-mask EPKTCNT ERXRDPTL/H ERXWRPTL/H.
static void printBytes(const uint8_t *p) {       // one USB write, so a host that is not reading stalls us once, not per byte
  char b[3 * DBG_LEN + 2], *q = b;
  for (uint8_t i = 0; i < DBG_LEN; i++) {
    uint8_t hi = p[i] >> 4, lo = p[i] & 15;
    *q++ = ' '; *q++ = hi < 10 ? '0' + hi : 'A' + hi - 10; *q++ = lo < 10 ? '0' + lo : 'A' + lo - 10;
  }
  *q++ = '\r'; *q++ = '\n';
  Serial.write((const uint8_t *)b, q - b);
}

static void printChip(const __FlashStringHelper *what, const uint8_t *s) {
  Serial.print(what); Serial.print(F(" at ")); Serial.print(millis() / 1000UL); Serial.print(F(" s, chip:"));
  printBytes(s);
}

static void printWhy() {
  Serial.print(F(", why=")); Serial.print(nvWhy); Serial.print(F(", chip:"));
  printBytes(nvDbg);
}

// The only way to reset EtherCard's private RX pointers (function-local statics in packetReceive()).
static void restartMcu(const __FlashStringHelper *why, uint8_t code) __attribute__((noreturn));
static void restartMcu(const __FlashStringHelper *why, uint8_t code) {
  nvWhy = code;
  encSnapshot(nvDbg);
  nvTime = (timeStatus() == timeNotSet) ? 0 : (uint32_t)now();
  if (nvStreak < 200) nvStreak++;            // all bookkeeping before the prints: a watchdog reset during a stalled
  if (nvTotal < 250) nvTotal++;              // print must still look like a self-restart and keep the evidence
  nvMagic = NV_MAGIC;
  Serial.print(F("Restarting MCU: "));
  Serial.print(why);
  printWhy();
  Serial.flush();                            // cli() below stops the 1 ms USB flush, so hand the FIFO over now
  cli();
  *(volatile uint16_t *)0x0800 = 0;          // boot key 0x7777 would hold Caterina for 8 s
  *(volatile uint16_t *)(RAMEND - 1) = 0;    // same key at the newer bootloader location
  wdt_enable(WDTO_15MS);
  for (;;) {}
}

// Shift that lengthens every restart window after consecutive self-restarts, so a restart loop slows down.
static uint8_t backoff() {
  return nvStreak > BACKOFF_MAX ? BACKOFF_MAX : nvStreak;
}

// End of the flash image (.text + .data), the same figure the IDE prints as "Sketch uses N bytes".
extern "C" char __data_load_end;
static uint16_t flashUsed() { return (uint16_t)(uintptr_t)&__data_load_end; }

static int freeRam() {
  extern int __heap_start, *__brkval;
  int v;
  return (int) &v - (__brkval == 0 ? (int) &__heap_start : (int) __brkval);
}

// Pulse the ENC28J60 hardware reset line (active-low). Harmless if RST isn't
// wired to ETH_RST_PIN; if it is, this gives the chip a clean reset, which
// helps recover a locked-up module far more reliably than a software re-init.
static void hardResetEthernet() {
#ifdef ETH_RST_PIN
  pinMode(ETH_RST_PIN, OUTPUT);
  digitalWrite(ETH_RST_PIN, LOW);    // assert active-low reset
  delay(5);
  digitalWrite(ETH_RST_PIN, HIGH);   // release
  delay(100);                        // let the oscillator/PHY start (proven timing)
#endif
}

// Write a byte to the ENC28J60 EWRPTL scratch register (bank 0) and read it
// back. EWRPTL is harmless to clobber (ether.begin() reinitialises it).
static uint8_t encScratch(uint8_t val) {
  digitalWrite(CS_PIN, LOW);
  SPI.transfer(0x40 | 0x02);   // WCR | EWRPTL
  SPI.transfer(val);
  digitalWrite(CS_PIN, HIGH);
  digitalWrite(CS_PIN, LOW);
  SPI.transfer(0x00 | 0x02);   // RCR | EWRPTL
  uint8_t v = SPI.transfer(0x00);
  digitalWrite(CS_PIN, HIGH);
  return v;
}

// Read a control register (RCR). Assumes an SPI transaction is already active.
static uint8_t encReadReg(uint8_t addr) {
  digitalWrite(CS_PIN, LOW);
  SPI.transfer(0x00 | (addr & 0x1F));   // RCR opcode
  uint8_t v = SPI.transfer(0x00);
  digitalWrite(CS_PIN, HIGH);
  return v;
}

// Bounded probe used BEFORE ether.begin(). Two checks, neither of which can
// hang:
//   1) SPI link solid? (write-readback two patterns — floating MISO can't fake)
//   2) Oscillator actually running? (poll ESTAT.CLKRDY for up to ~50 ms)
// Check (2) is the important one: SPI register access is clocked by SCK and
// works even if the ENC's 25 MHz crystal is dead, so without it ether.begin()
// would spin forever on CLKRDY. If this returns false we stay OFFLINE and keep
// running the thermometer.
static bool enc28j60Responds() {
  pinMode(CS_PIN, OUTPUT);
  digitalWrite(CS_PIN, HIGH);
  SPI.begin();
  SPI.beginTransaction(SPISettings(8000000, MSBFIRST, SPI_MODE0));
  bool spiOk = (encScratch(0xAB) == 0xAB) && (encScratch(0x54) == 0x54);
  bool clkrdy = false;
  for (uint8_t i = 0; spiOk && !clkrdy && i < 50; i++) {
    uint8_t es = encReadReg(0x1D);                  // ESTAT
    if (es != 0xFF && (es & 0x01)) clkrdy = true;   // CLKRDY (oscillator ready)
    else delay(1);
  }
  SPI.endTransaction();
  if (spiOk && !clkrdy)
    Serial.println(F("ENC oscillator not ready (CLKRDY low) - crystal/power fault"));
  return spiOk && clkrdy;
}
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
void loop() {
  Watchdog.reset();

  if (ethReady && Serial.available() && Serial.read() == 'd') {   // send "d" over USB for a chip snapshot on demand
    uint8_t s[DBG_LEN];
    encSnapshot(s);
    printChip(F("chip"), s);
  }

  if (ethReady) {
    // --- network is up: service the stack, web, NTP, link health ---
    word len = ether.packetReceive();
    if (len) {
      rxSeen = true;
      if (isGatewayArpReply(Ethernet::buffer, len)) {   // before packetLoop() touches the buffer
        lastAck = millis();
        if (probeMiss) { probeMiss = false; Serial.println(F("Gateway ARP answered again")); }
      }
    }
    word pos = ether.packetLoop(len);

    // NTP answer (UDP) arrives outside the TCP path; check the raw buffer.
    uint32_t ntp = 0;
    if (len && ether.ntpProcessAnswer(&ntp, NTP_SRCPORT)) {
      setTime((time_t)(ntp - NTP_EPOCH_1900));
      timeSynced = true;
      Serial.println(F("NTP sync OK"));
    }

    // Serve the web UI / API.
    if (pos) {
      bfill = ether.tcpOffset();
      char* data = (char *) Ethernet::buffer + pos;
      // Home is matched exactly (trailing space = root only). Assets are matched
      // as prefixes (no trailing space) so cache-busting query strings like
      // "GET /main.js?v=4" still route correctly.
      if      (checkUrl(F("GET / "),           data)) homePage(bfill);
      else if (checkUrl(F("GET /main.css"),    data)) mainCss(bfill);
      else if (checkUrl(F("GET /main.js"),     data)) mainJs(bfill);
      else if (checkUrl(F("GET /det.js"),      data)) detJs(bfill);
      else if (checkUrl(F("GET /favicon.svg"), data)) faviconSvg(bfill);
      else if (checkUrl(F("GET /list.json"),   data)) listJson(bfill);
      else bfill.print(F("HTTP/1.0 404 Not Found\r\nContent-Type: text/html\r\n\r\n<h1>404 Not Found</h1>"));
      ether.httpServerReply(bfill.position());
    }

    serviceTime();

    // Probe the gateway on a timer; its reply proves a short frame got out and one came back.
    if (linkUp && millis() - lastProbe > PROBE_MS) {
      if (!probeMiss && (int32_t)(lastProbe - lastAck) > 0) {   // the previous probe got no reply
        probeMiss = true;
        uint8_t s[DBG_LEN];
        encSnapshot(s);
        printChip(F("Gateway ARP unanswered"), s);
      }
      lastProbe = millis();
      probeGateway();
    }

    // On a timer: first prove the chip still responds (bounded), THEN it's safe
    // to read the PHY link. If it stopped responding, re-init (MCU restart after traffic).
    if (millis() - lastLinkChk > LINK_CHECK_MS) {
      lastLinkChk = millis();
      if (!enc28j60Healthy()) {
        if (!rxSeen || millis() > (MIN_UPTIME_MS << backoff())) {
          Serial.println(F("NIC stopped responding"));
          ethReady = bringUpEthernet();      // probe-protected; may drop to OFFLINE
          linkUp = false;
        }
      } else {
        bool up = ether.isLinkUp();          // safe now: chip just proved responsive
        if (up != linkUp) { Serial.print(up ? F("Link UP at ") : F("Link DOWN at ")); Serial.println(millis() / 1000UL); }
        if (up && !linkUp) {
          rxSeen = true;                     // a linked chip may already hold frames
          armProbe();                        // link is back: restart the silence clock
          ether.setGwIp(gwip);               // re-arm the gateway MAC lookup so NTP has somewhere to go
        }
        linkUp = up;
        if (up) lastLinkUp = millis();
        if (auditOk && millis() - lastAudit > AUDIT_MS) {   // e.g. lost padding or filter bits: the link still looks fine
          lastAudit = millis();
          uint8_t s[DBG_LEN];
          encSnapshot(s);
          if (!ovfSeen && s[1] != 0xFF && ((s[1] & 0x40) || (s[2] & 0x01))) {   // ESTAT.BUFER or EIR.RXERIF since the chip reset
            ovfSeen = true;
            printChip(F("RX overflow flag"), s);
          }
          if (chipGood(s)) auditBad = 0;
          else if (++auditBad > 1 && millis() > (MIN_UPTIME_MS << backoff())) restartMcu(F("chip registers changed"), 4);
        }
      }
    }
    // Only while the link never came up: an in-place re-init after traffic desyncs EtherCard's RX pointers.
    if (ethReady && !linkUp && !rxSeen && millis() - lastLinkUp > ETH_REINIT_MS) {
      Serial.println(F("No link since boot -> re-init ENC28J60"));
      ethReady = bringUpEthernet();
      lastLinkUp = millis();
    }
    // Link lost for good after it was up: a restart is the only safe chip re-init.
    if (ethReady && !linkUp && rxSeen && millis() - lastLinkUp > (LINK_DOWN_RESTART_MS << backoff())) {
      restartMcu(F("no link"), 1);
    }
    // Link up but the gateway never answers our ARP: a short frame is not getting out or back.
    if (ethReady && linkUp && millis() - lastAck > ((ovfSeen ? SILENT_FAST_MS : SILENT_RESTART_MS) << backoff())) {
      restartMcu(F("no gateway ARP reply with link up"), 2);
    }

    // !probeMiss: the link-up grace in lastAck must not forget a streak while the gateway is still silent.
    if (nvStreak && millis() > STREAK_CLEAR_MS && !probeMiss && millis() - lastAck < 2 * PROBE_MS) nvStreak = 0;
  } else {
    // --- OFFLINE: retry bringing up the NIC periodically (probe-protected) ---
    linkUp = false;
    if (lastEthTry == 0 || millis() - lastEthTry > ETH_RETRY_MS) {
      lastEthTry = millis();
      ethReady = bringUpEthernet();
    }
  }

  // --- these always run, independent of Ethernet (the monitor's real job) ---

  serviceSensor();                  // async temperature read — never blocks

  if (millis() - lastLcd > LCD_REFRESH_MS) {
    lastLcd = millis();
    updateLcd();
  }

#if DEBUG
  // Status heartbeat over Serial (compiled out when DEBUG = 0). Integer temp
  // print, so it doesn't pull the float-to-string code back in.
  if (millis() - lastStatus > 3000) {
    lastStatus = millis();
    int c10 = (int)(celsius * 10);
    Serial.print(F("alive eth="));  Serial.print(ethReady ? F("up") : F("off"));
    Serial.print(F(" link="));      Serial.print(linkUp ? F("UP") : F("DOWN"));
    Serial.print(F(" ackage="));    Serial.print((millis() - lastAck) / 1000UL);
    Serial.print(F(" ntp="));       Serial.print(timeSynced ? F("ok") : F("no"));
    Serial.print(F(" temp="));      Serial.print(c10 / 10); Serial.write('.'); Serial.print(abs(c10 % 10));
    Serial.print(F(" free="));      Serial.println(freeRam());
  }
#endif
}

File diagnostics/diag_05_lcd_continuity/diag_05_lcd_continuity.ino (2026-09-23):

/*
 * diag_05_lcd_continuity -- Stage A diagnostic: raw pin-level continuity
 * check for the 16x2 LCD control/data lines, with NO dependency on the LCD
 * actually working. For when diag_02_lcd still shows only blocks/blank
 * after reflowing the solder joints, to find out whether each wire is
 * really reaching the LCD, one line at a time.
 *
 * Does NOT use the LiquidCrystal library, just raw digitalWrite() so a
 * multimeter can confirm each signal arrives at the LCD header pin, not
 * just the Arduino pin (a cold joint can look fine at the Arduino end and
 * still be open at the LCD end).
 *
 * Method: this sketch holds ONE line HIGH for 3s, then LOW for 1s, then
 * moves to the next line, announcing each step over Serial (9600 baud).
 * Set a multimeter to DC volts, black probe on Arduino GND, red probe on
 * the LCD-SIDE header pin named in the current message (not the Arduino
 * pin). It should read ~5V then ~0V in step with the messages. A pin that
 * stays at 0V or floats at the LCD end while the message says HIGH means
 * that wire or joint is still broken, even if it reads fine at the
 * Arduino pin itself.
 *
 * RW, VSS, VDD and V0 are not driven by any Arduino pin (RW -> GND,
 * VSS -> GND, VDD -> 5V, V0 -> contrast pot wiper), so check those with
 * the multimeter in continuity/resistance mode, power OFF, separately.
 *
 * Pin 13 (built-in LED) blinks throughout as a "sketch is really running"
 * heartbeat. If it is not blinking, the upload did not take, or the board
 * is not running this sketch, check that before anything else.
 */

#include <Arduino.h>

struct LcdLine {
  uint8_t arduinoPin;
  const char *lcdName;
  uint8_t lcdPin;
};

const LcdLine LINES[] = {
  {7, "RS", 4},
  {6, "E",  6},
  {5, "D4", 11},
  {4, "D5", 12},
  {3, "D6", 13},
  {2, "D7", 14},
};
const uint8_t N = sizeof(LINES) / sizeof(LINES[0]);

static void heartbeatDelay(unsigned long ms) {
  unsigned long start = millis();
  while (millis() - start < ms) {
    digitalWrite(LED_BUILTIN, ((millis() / 250) % 2) ? HIGH : LOW);
  }
}

static void driveAndAnnounce(const LcdLine &l, bool high) {
  digitalWrite(l.arduinoPin, high ? HIGH : LOW);
  Serial.print(F("Driving "));
  Serial.print(l.lcdName);
  Serial.print(F(" (Arduino D"));
  Serial.print(l.arduinoPin);
  Serial.print(F(" -> LCD pin "));
  Serial.print(l.lcdPin);
  Serial.print(F(") = "));
  Serial.println(high ? F("HIGH (~5V)") : F("LOW (~0V)"));
}

void setup() {
  Serial.begin(9600);
  unsigned long t0 = millis();
  while (!Serial && millis() - t0 < 3000) {}
  Serial.println(F("=== diag_05_lcd_continuity ==="));
  Serial.println(F("Probe the LCD-SIDE pin named below with a multimeter (DC volts,"));
  Serial.println(F("black lead on Arduino GND). It should track each HIGH/LOW below."));
  Serial.println();

  pinMode(LED_BUILTIN, OUTPUT);
  for (uint8_t i = 0; i < N; i++) {
    pinMode(LINES[i].arduinoPin, OUTPUT);
    digitalWrite(LINES[i].arduinoPin, LOW);
  }
}

void loop() {
  for (uint8_t i = 0; i < N; i++) {
    driveAndAnnounce(LINES[i], true);
    heartbeatDelay(3000);
    driveAndAnnounce(LINES[i], false);
    heartbeatDelay(1000);
  }
  Serial.println(F("--- cycle complete, repeating ---"));
  Serial.println();
}

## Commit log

2015-01-27 Plain HTTP page serving the temperature
2026-06-28 Add Stage A diagnostic sketches (blink, LCD, DS18B20, Ethernet)
2026-06-28 Modernize: NTP clock, SleepyDog watchdog, ENC28J60 RST resilience, async sensor, original web UI
2026-09-23 README: split the LCD pin map into its own table with header pin numbers
    The combined Signal/Leonardo-pin table crammed four LCD signals into
    slash-separated cells with no LCD header pin numbers at all, unreadable
    at a glance and missing the power/contrast/backlight pins entirely.
2026-09-23 Add enclosure design files and credit Daniel Wiśniewski
    Full Fusion 360 assembly (STEP) and the two printable parts (STL) for
    the 3D-printed enclosure, plus README/LICENSE credit for the
    brightness/contrast potentiometer icons adapted from Flaticon.
    [Termo_box.stl, Termo_lid.stl]
2026-09-23 Add diagnostics for LCD continuity, live sensor status, and combined checks
    diag_05: raw pin-level continuity test for the LCD control/data lines,
    no LiquidCrystal library, for probing wiring with a multimeter without
    depending on the display already working.
    diag_06: LCD shows live DS18B20 detection status, rescanned every
    cycle, for probing/reseating the sensor while watching the panel.
    diag_07: combines diag_06 with Ethernet bring-up and a minimal real
    HTTP response, so sensor and network reachability can both be checked
    from one flash instead of swapping sketches.
    [diag_05_lcd_continuity.ino, diag_06_sensor_live.ino, diag_07_lcd_sensor_ethernet.ino]
2026-09-23 Fix NTP DNS lookup freezing the whole loop, use a fixed server IP
    ether.dnsLookup() blocks for up to ~30s on failure, and the watchdog is
    deliberately paused around that call, so on a network where the DNS
    query never gets a response the LCD (not just networking) freezes for
    each retry attempt, reproducing on every reconnect since haveNtpServer
    resets on every bringUpEthernet() call.
    The actual time request, ether.ntpRequest(), was already non-blocking,
    DNS resolution was the only real risk. Replaced the pool.ntp.org
    hostname lookup with a fixed NTP_SERVER_IP (Google Public NTP),
    removing dnsFails/lastDnsTry/NTP_MAX_DNS_FAILS and the whole
    backoff/give-up logic along with it. Confirmed live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
    [TempServerJQuery.ino]
2026-09-26 Make the network path self-recovering, add EU summer time and probe hot-plug
    Field failure of 2026-09-25: the ENC28J60 kept receiving but stopped
    answering ARP and TCP. EtherCard keeps its RX pointers in function-local
    statics that ether.begin() cannot reset, so an in-place re-init after
    traffic desyncs the receive path. Only an MCU restart clears them.
    Network:
    - Never re-init the NIC in place once a frame was seen. A lost link is
    waited out; after 10 minutes down the MCU restarts through the watchdog.
    - Liveness proof is an ARP reply from the gateway (hand-built who-has every
    30 s). No reply for 5 minutes with the link up restarts the MCU.
    - Consecutive restarts double the windows up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
    [TempServerJQuery.ino]
2026-09-26 Add public access through an nginx cache and a Cloudflare tunnel on the Pi
    The board's page is now reachable at https://thermometer.bmroz.eu without
    forwarding a router port. Visitors are answered by an nginx cache on a
    Raspberry Pi (list.json 10 s, page 60 s, assets 10 min), which proxies only
    the board's six URLs, holds at most 2 connections open to it and rate-limits
    each visitor. cloudflared makes only outbound connections.
    pi/ holds the nginx config, a cloudflared config example without secrets and
    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
2026-09-26 Read flash use from the linker, extend the chip snapshot, and write ERXRDPT odd after init
    Diagnostics for the ENC28J60 failures seen on 2026-09-25 and 2026-09-26:
    - /list.json gains "flash", read from the linker (__data_load_end) so it matches
    the IDE's "Sketch uses N bytes"; the footer shows it in KB instead of a hand-set
    constant. ASSET_VER is 9.
    - The chip snapshot in "dbg" grows from 8 to 12 bytes: EPKTCNT and the receive
    buffer read and write pointers (ERXRDPT, ERXWRPT) are added.
    - Serial prints link changes with the uptime, the snapshot when the first gateway
    ARP probe goes unanswered, a one-time "RX overflow flag" line, and a snapshot
    whenever "d" is sent over USB. Dumps g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
    [TempServerJQuery.ino]
2026-09-26 Split the README into docs pages, add enclosure photos and the 2026-09-26 findings
    The README is now about 300 lines instead of 430. The detail moved verbatim into
    docs/: how-it-works, resilience, hardware-notes, changes-since-2015 and flashing,
    each linked from a short summary in the README.
    Also:
    - Enclosure photos (knobs, inside, lid, mid-wiring and just before closing), with
    GPS and camera metadata stripped.
    - A note that the DS18B20 probe plugs in through a 3.5 mm jack, with the pinout
    that keeps hot-plug shorts harmless.
    - Documented the second field failure, the first recovery by the restart ladder,
    how to read the 12-byte chip snapshot, the ERXRDPT errata fix, and the
    suspec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
2026-09-27 docs: update the web UI screenshot to the current footer and detail panel
2026-09-27 Shorten the link-down restart window and cap the backoff at 4x
    Last night's failures showed outages up to 84 minutes: consecutive
    self-restarts doubled every recovery window up to 16 times, so a chip
    stuck offline could wait 160 minutes before the next attempt. Cap the
    backoff at 4x instead, and cut LINK_DOWN_RESTART_MS from 10 minutes to
    3, so the worst case drops to about 20 minutes. Already flashed and
    running.
    [TempServerJQuery.ino]
2026-09-27 Stop naming a specific network, and correct the recovery timings in the docs
    The board no longer lives on an office LAN, so drop that wording from
    the intro, the History section, the config table and the repository
    layout in favour of network-agnostic phrasing.
    Also correct docs/resilience.md and the README to the timings actually
    running on the board after the backoff change: 3 minutes without a
    link (was 10), restarts stretching up to 4 times (was 16), a bench
    board with no gateway settling at 20 minutes (was 80).
    Refreshed the web UI screenshot.
2026-09-27 README: rename to rozna-thermometer, drop redundant credit, add 'sensor'
